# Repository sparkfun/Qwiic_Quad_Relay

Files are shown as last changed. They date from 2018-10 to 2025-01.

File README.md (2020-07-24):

SparkFun Qwiic Quad Relay
========================================

SparkFun Qwiic Quad Relay (https://www.sparkfun.com/products/16566)

[*SparkFun Qwiic Quad Relay (COM-16566)*](https://www.sparkfun.com/products/16566)

The Qwiic Quad Relay is a product designed for switching not one, but **four** high powered devices, from your Arduino or other low powered microcontroller using I<sup>2</sup>C. It's rocking four [relays](https://www.sparkfun.com/products/100) on its' PCB rated up to 5 Amps per channel at 250VAC. Each channel is sporting its own colored LED and silk for easy identification, and has screw terminals for easy connection.  

The board is made to integrate easily into the [Qwiic environment](https://www.sparkfun.com/qwiic) with Qwiic connectors on each side for easy daisy chaining. At the heart of the product is an ATtiny84 with its own I<sup>2</sup>C address awaiting for I<sup>2</sup>C commands that are designated to turn on and off individual channels or _all_ the channels at once! All of this is detailed nicely in provided example code, which also walks you through changing the boards single I<sup>2</sup>C address. There is a four pin header broken out for those of you not taking advantage of the Qwiic connector.

The onboard barrel jack is rated for wall warts in the range, 7-15V but there is a jumper on the underside in the case that your wall wart is 5V. Messing with such high voltage can be dangerous! We've included many safety precautions onto the PCB including, wide traces designed for high amperage, ground isolation between the relay and other circuitry, and a milled out area around the common pin of the relay.

Repository Contents
-------------------

* **/Firmware** - Latest firmware and examples. 
* **/Arduino Example** - Examples on how to use the product with buttons and switches, with hardware interrupts and without.
* **/Hardware** - Eagle design files (.brd, .sch)

Documentation
--------------

* **[Hookup Guide](https://learn.sparkfun.com/tutorials/qwiic-quad-relay-hookup-guide)** - Basic hookup guide

Arduino Library
--------------
* **[SparkFun Qwiic Relay Ardruino Library](https://github.com/sparkfun/SparkFun_Qwiic_Relay_Arduino_Library)** - SparkFun Arduino Library for controlling the Qwiic Single and Quad Relay

License Information
-------------------

This product is _**open source**_! 

Please review the LICENSE.md file for license information. 

If you have any questions or concerns on licensing, please contact technical support on our [SparkFun forums](https://forum.sparkfun.com/viewforum.php?f=152).

Please use, reuse, and modify these files as you see fit. Please maintain attribution to SparkFun Electronics and release under the same license.

Distributed as-is; no warranty is given.

- Your friends at SparkFun.

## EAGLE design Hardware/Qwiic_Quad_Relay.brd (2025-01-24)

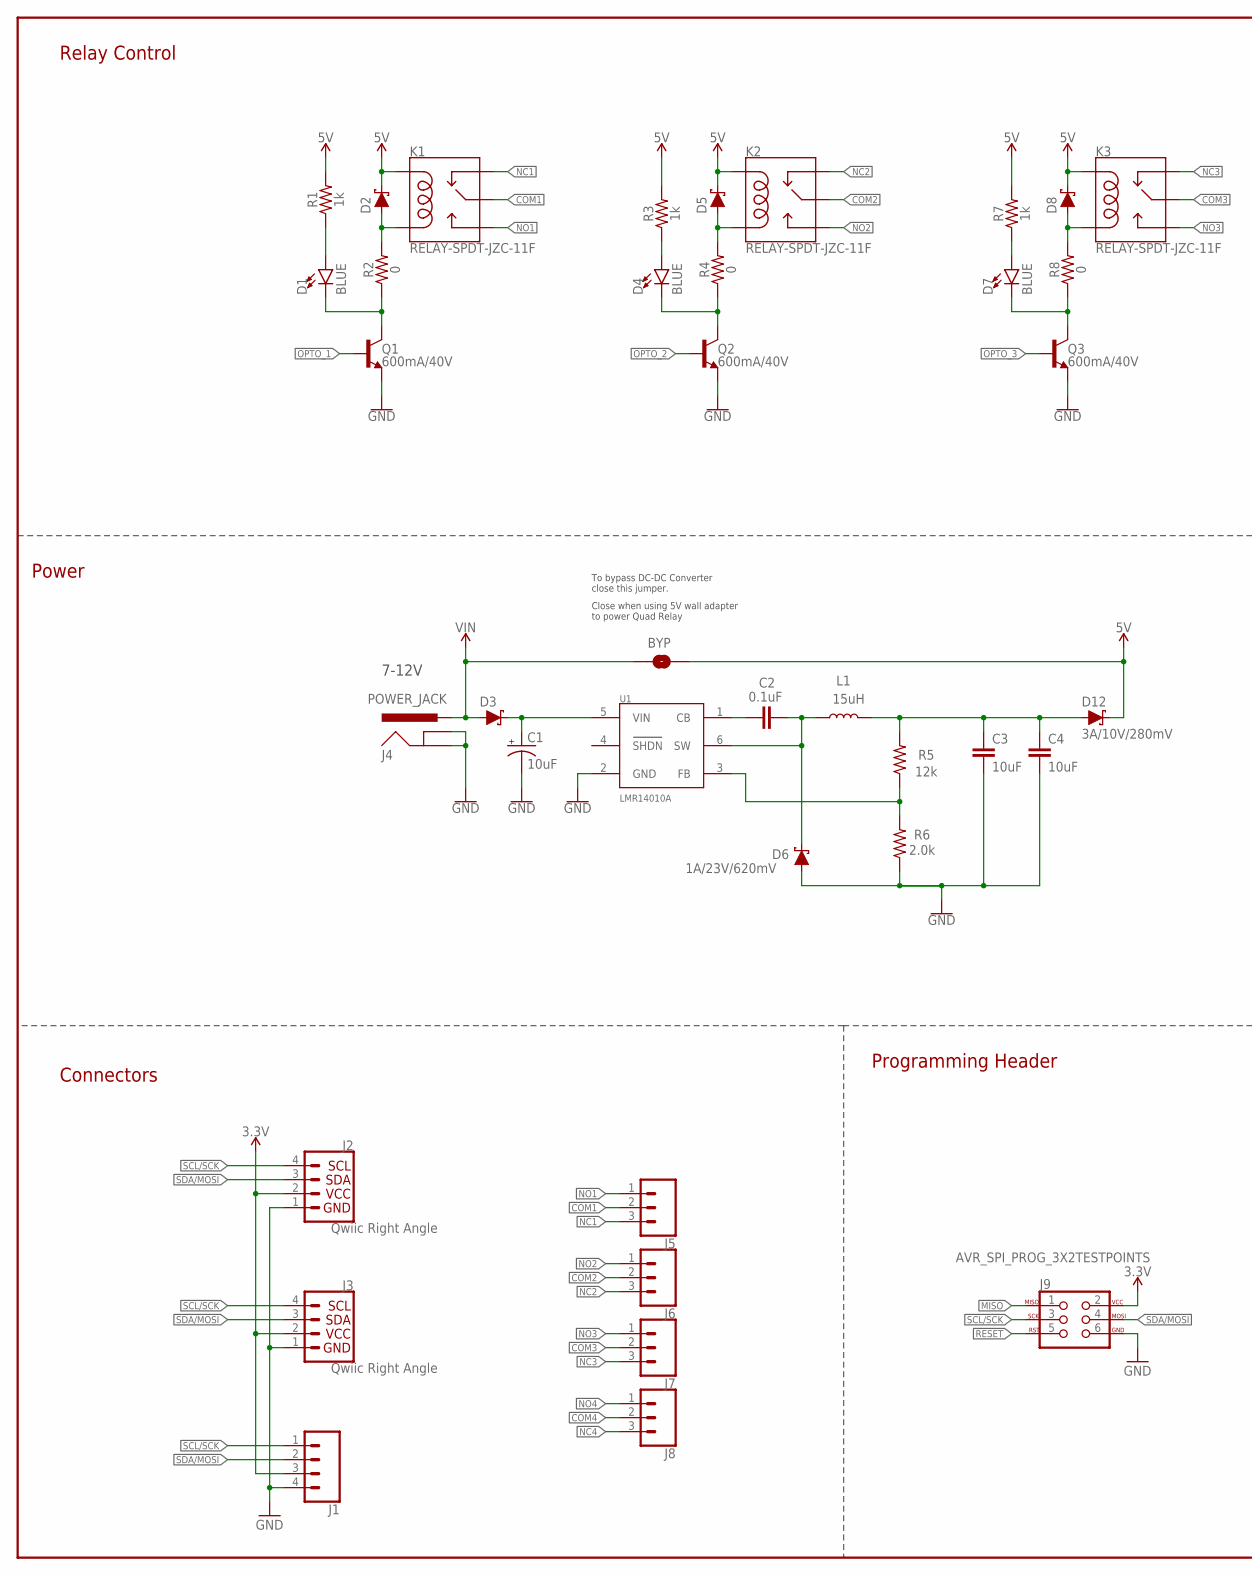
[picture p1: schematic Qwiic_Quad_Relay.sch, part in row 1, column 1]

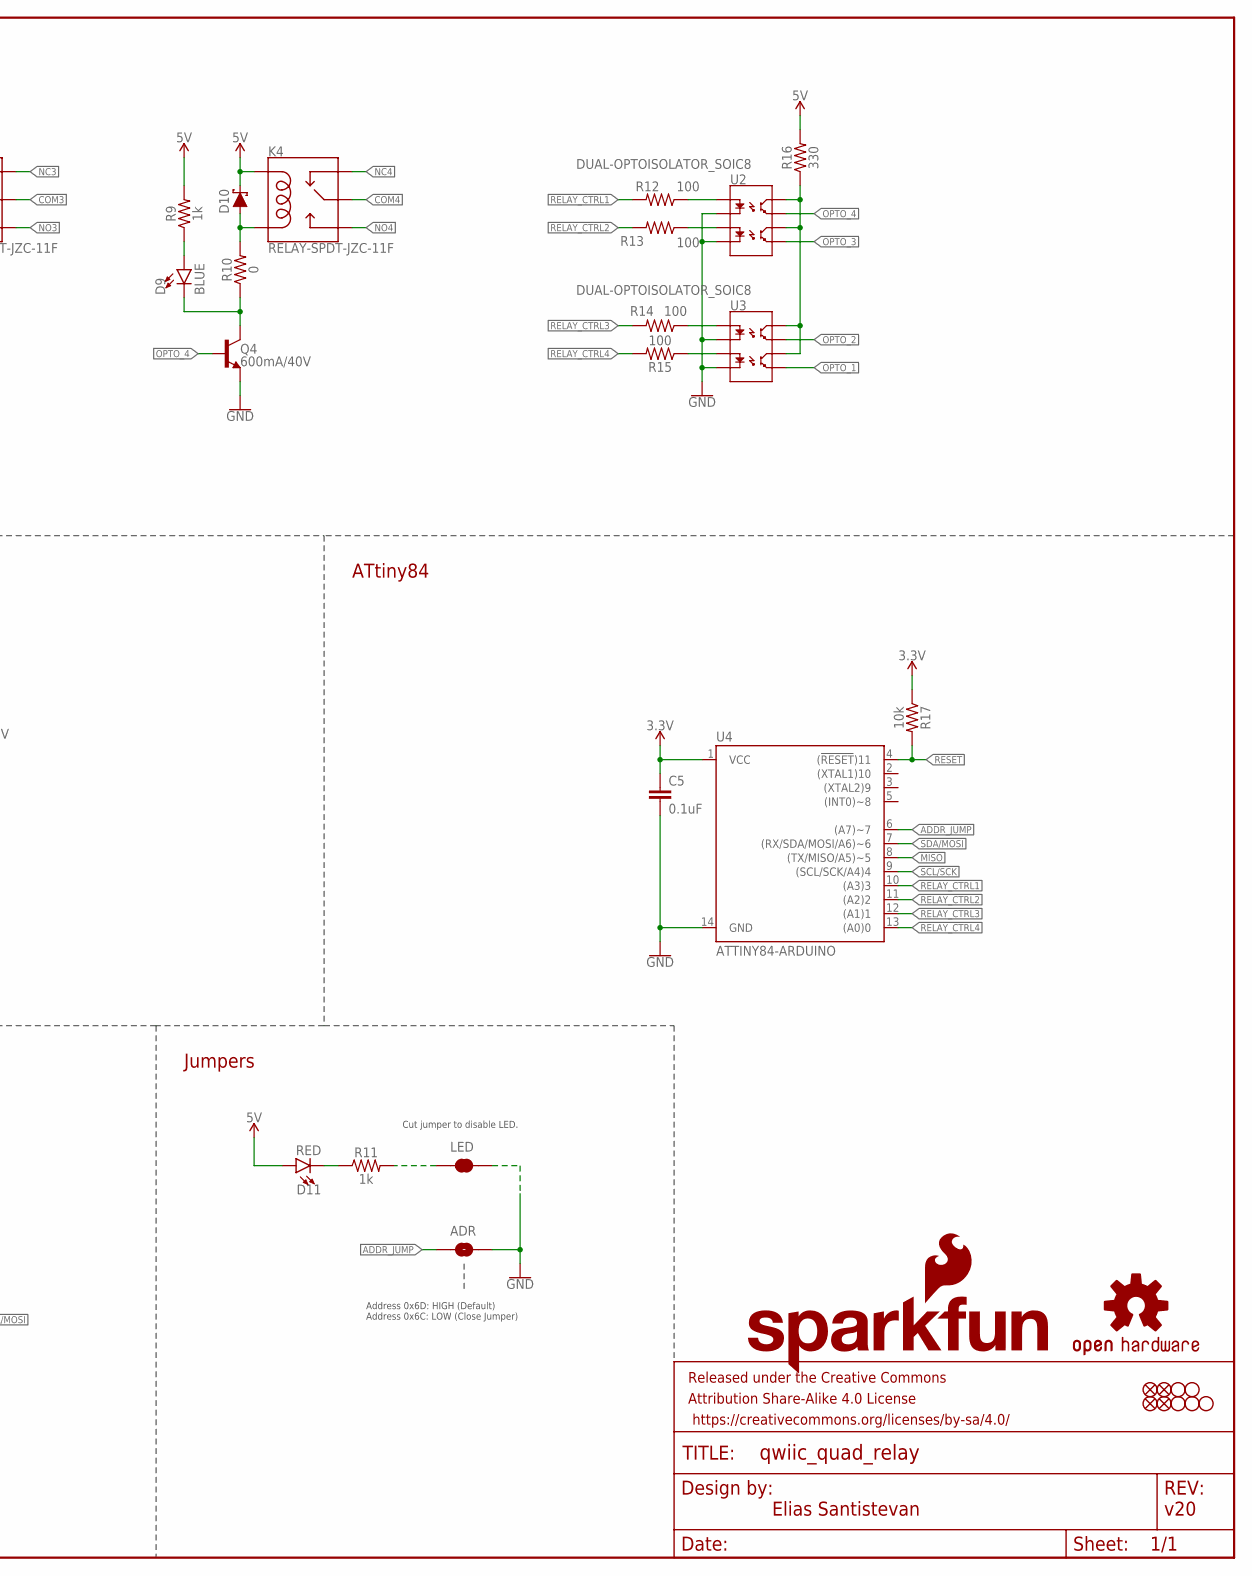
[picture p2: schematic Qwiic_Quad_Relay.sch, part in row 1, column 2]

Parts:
ADR: JUMPER-SMT_2_NO_SILK; SMT-JUMPER_2_NO_SILK
BYP: JUMPER-SMT_2_NO_SILK; SMT-JUMPER_2_NO_SILK
C1: 10uF; EIA3528
C2: 0.1uF; 0402
C3, C4: 10uF; 0603
C5: 0.1uF; 0603
D1, D4, D7, D9: BLUE; LED-0603
D2, D5, D6, D8, D10: 1A/23V/620mV; SOD-323
D3: 1A/40V/500mV; SMA-DIODE
D11: RED; LED-0603
D12: 3A/10V/280mV; SOD-323
FD1, FD2, FD3, FD4: FIDUCIAL1X2; FIDUCIAL-1X2
FRAME1: FRAME-LEDGER; CREATIVE_COMMONS
J1: CONN_041X04_NO_SILK_NO_POP; 1X04_NO_SILK
J2, J3: Qwiic Right Angle; JST04_1MM_RA
J4: POWER_JACK; POWER_JACK_PTH
J5, J6, J7, J8: CONN_03-SCREW-5MM; SCREWTERMINAL-5MM-3
J9: AVR_SPI_PROG_3X2TESTPOINTS; 2X3_TEST_POINTS
JP1, JP4, JP5, JP6, JP7: STAND-OFF
K1, K2, K3, K4: RELAY-SPDT-JZC-11F; RELAY-JZC
L1: 15uH; INDUCTOR_15UH
LED: JUMPER-SMT_2_NC_TRACE_SILK; SMT-JUMPER_2_NC_TRACE_SILK
LOGO1: SFE_LOGO_NAME_FLAME.1_INCH; SFE_LOGO_NAME_FLAME_.1
LOGO2: OSHW-LOGOS; OSHW-LOGO-S
Q1, Q2, Q3, Q4: 600mA/40V; SOT23-3
R1, R3, R7, R9, R11: 1k; 0603
R2, R4, R8, R10: 0; 0603
R5: 12k; 0603
R6: 2.0k; 0603
R12, R13, R14, R15: 100; 0603
R16: 330; 0603
R17: 10k; 0603
U1: LMR14010A; SOT23-6
U2, U3: DUAL-OPTOISOLATOR_SOIC8; SO08
U4: ATTINY84-ARDUINO; SO14

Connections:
3.3V: C5.1, J1.3, J2.2, J3.2, J9.2, R17.1, U4.1 (VCC)
5V: BYP.2, D2.C, D5.C, D8.C, D10.C, D11.A, D12.C, K1.5 (COIL1), K2.5 (COIL1), K3.5 (COIL1), K4.5 (COIL1), R1.2, R3.2, R7.2, R9.2, R16.2
5V_OUT: C3.1, C4.1, D12.A, L1.P2 (2), R5.2
!RESET: J9.5, R17.2, U4.4 ((!RESET!)11)
ADDR_JUMP: ADR.1, U4.6 ((A7)~7)
CB: C2.1, U1.1 (CB)
COM1: J5.2, K1.4 (MAIN)
COM2: J6.2, K2.4 (MAIN)
COM3: J7.2, K3.4 (MAIN)
COM4: J8.2, K4.4 (MAIN)
FB: R5.1, R6.2, U1.3 (FB)
GND: ADR.2, C1.C (-), C3.2, C4.2, C5.2, D6.A, J1.4, J2.1, J3.1, J4.GND, J4.GNDBREAK, J9.6, LED.1, Q1.2 (E), Q2.2 (E), Q3.2 (E), Q4.2 (E), R6.1, U1.2 (GND), U2.2 (C1), U2.4 (C2), U3.2 (C1), U3.4 (C2), U4.14 (GND)
MISO: J9.1, U4.8 ((TX/MISO/A5)~5)
unnamed: D1.A, R1.1
unnamed: D1.C, Q1.3 (C), R2.1
unnamed: R15.1, U3.3 (A2)
unnamed: D4.A, R3.1
unnamed: R14.1, U3.1 (A1)
unnamed: R16.1, U2.6 (CL2), U2.8 (CL1), U3.6 (CL2), U3.8 (CL1)
unnamed: D7.A, R7.1
unnamed: D9.A, R9.1
unnamed: R12.1, U2.1 (A1)
unnamed: D2.A, K1.1 (COIL2), R2.2
unnamed: R13.1, U2.3 (A2)
unnamed: D4.C, Q2.3 (C), R4.1
unnamed: D11.C, R11.1
unnamed: LED.2, R11.2
unnamed: D7.C, Q3.3 (C), R8.1
unnamed: D9.C, Q4.3 (C), R10.1
unnamed: D5.A, K2.1 (COIL2), R4.2
unnamed: D8.A, K3.1 (COIL2), R8.2
unnamed: D10.A, K4.1 (COIL2), R10.2
NC1: J5.3, K1.2 (NC)
NC2: J6.3, K2.2 (NC)
NC3: J7.3, K3.2 (NC)
NC4: J8.3, K4.2 (NC)
NO1: J5.1, K1.3 (NO)
NO2: J6.1, K2.3 (NO)
NO3: J7.1, K3.3 (NO)
NO4: J8.1, K4.3 (NO)
OPTO_1: Q1.1 (B), U3.5 (EM2)
OPTO_2: Q2.1 (B), U3.7 (EM1)
OPTO_3: Q3.1 (B), U2.5 (EM2)
OPTO_4: Q4.1 (B), U2.7 (EM1)
RELAY_CTRL1: R12.2, U4.10 ((A3)3)
RELAY_CTRL2: R13.2, U4.11 ((A2)2)
RELAY_CTRL3: R14.2, U4.12 ((A1)1)
RELAY_CTRL4: R15.2, U4.13 ((A0)0)
SCL/SCK: J1.1, J2.4, J3.4, J9.3, U4.9 ((SCL/SCK/A4)4)
SDA/MOSI: J1.2, J2.3, J3.3, J9.4, U4.7 ((RX/SDA/MOSI/A6)~6)
SW: C2.2, D6.C, L1.P1 (1), U1.6 (SW)
VIN: BYP.1, D3.A, J4.PWR
VIN_DC_DC: C1.A (+), D3.C, U1.5 (VIN)

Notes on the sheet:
Elias Santistevan
v20
Relay Control
Connectors
ATtiny84
Programming Header
Power
Address 0x6D: HIGH (Default) Address 0x6C: LOW (Close Jumper)
7-12V
Cut jumper to disable LED.
Jumpers
To bypass DC-DC Converter close this jumper.
Close when using 5V wall adapter to power Quad Relay

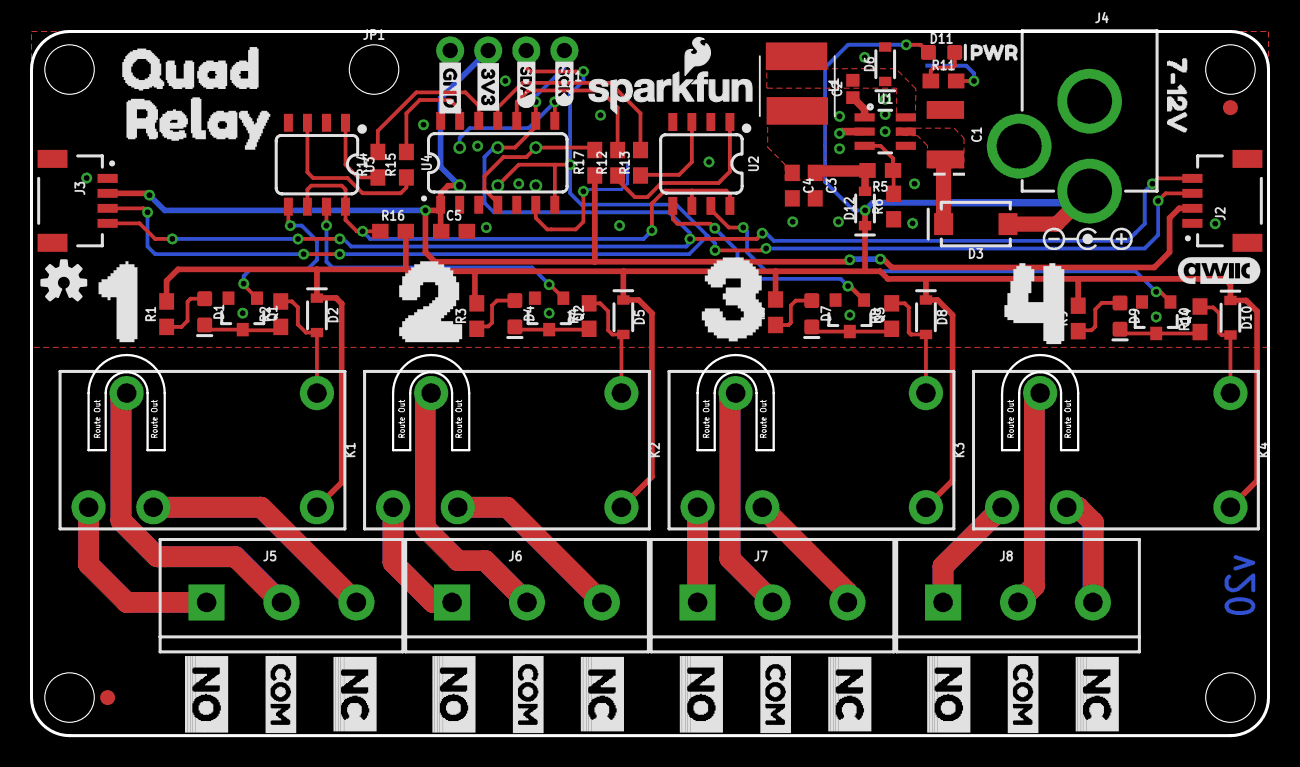
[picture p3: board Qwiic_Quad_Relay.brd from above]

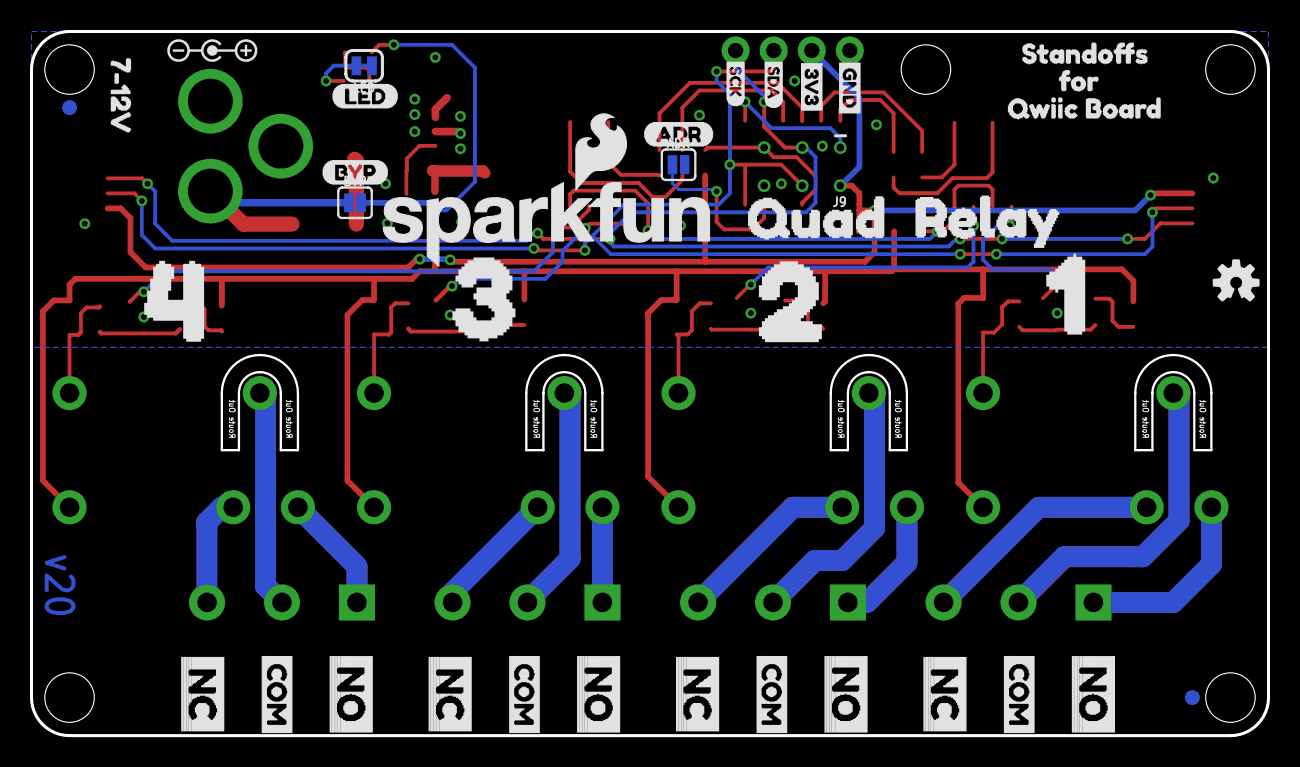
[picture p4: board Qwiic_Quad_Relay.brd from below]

Board: 2 copper layers, 82.5 x 47.0 mm, 129 parts (38 on the bottom side), 53 nets.

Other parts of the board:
U$1, U$49: 7#12V0
U$2, U$40: 20
U$3, U$39: 10
U$4, U$41: 30
U$5, U$42: 40
U$6, U$43: QUAD0
U$7, U$44: RELAY0
U$8, U$48: SCK-[)-03
U$9, U$45: GND-03
U$10, U$12: 3V3-03
U$11, U$47: SDA0
U$13: OSHW-LOGO-S
U$14: BYP
U$15, U$18, U$21, U$24, U$27, U$30, U$33, U$36: NO0
U$16, U$19, U$22, U$25, U$28, U$31, U$34, U$37: COM0
U$17, U$20, U$23, U$26, U$29, U$32, U$35, U$38: NC0
U$46: PWR_TO
U$50: STANDOFFS0
U$51, U$54: POLARITY_MARKING_CENTER_POSITIVE#JPG
U$52: FOR1
U$53: LED
U$55: QWIIC_5.5MM
U$56: ADR-()-04
U$57: SFE_LOGO_NAME_FLAME_.2
U$58: QWIIC_BOARD2

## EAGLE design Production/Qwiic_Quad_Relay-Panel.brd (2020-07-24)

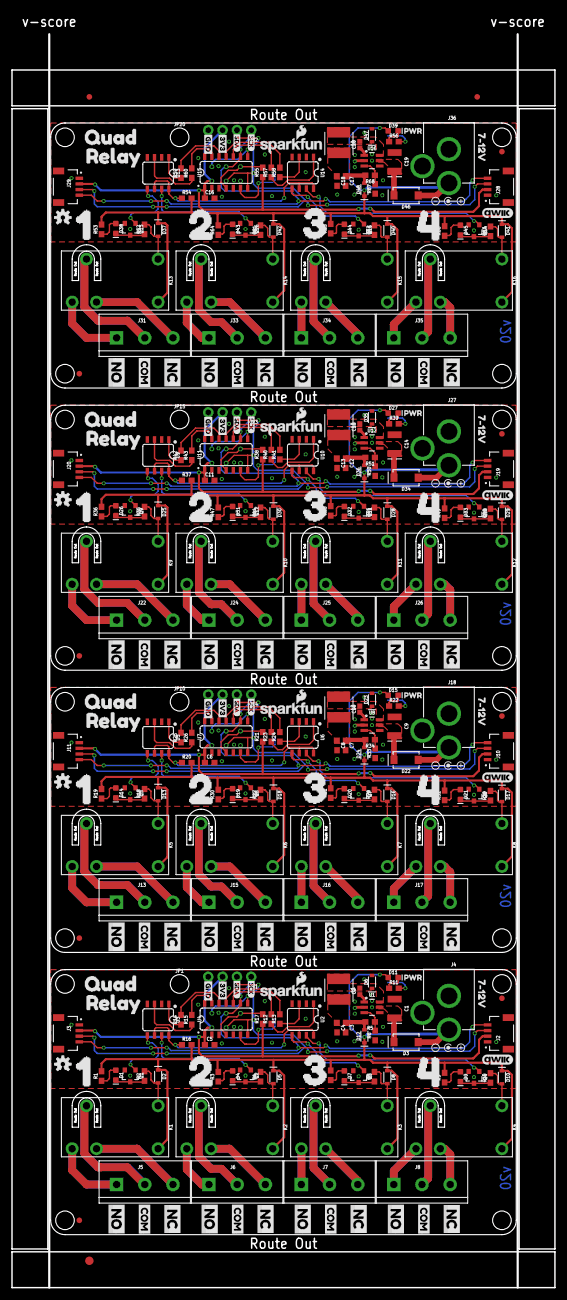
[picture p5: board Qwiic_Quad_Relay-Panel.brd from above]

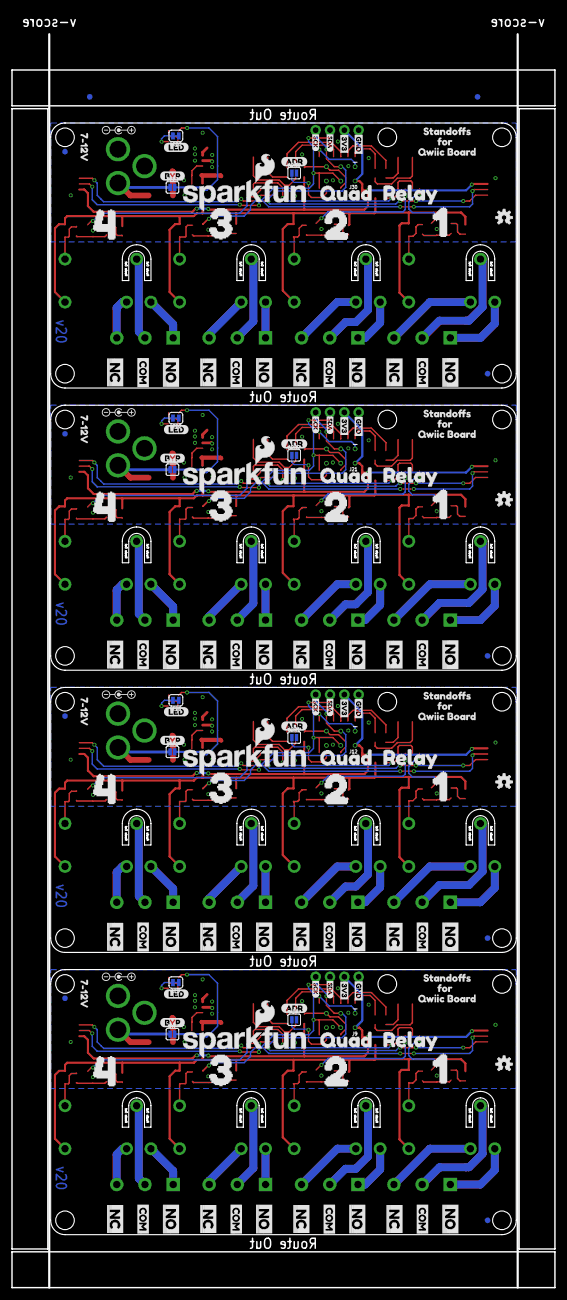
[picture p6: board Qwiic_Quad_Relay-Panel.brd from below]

Board: 2 copper layers, 96.3 x 222.2 mm, 517 parts (154 on the bottom side), 212 nets.

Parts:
ADR, ADR1, ADR2, ADR3: JUMPER-SMT_2_NO_SILK; SMT-JUMPER_2_NO_SILK
BYP, BYP1, BYP2, BYP3: JUMPER-SMT_2_NO_SILK; SMT-JUMPER_2_NO_SILK
C1, C9, C14, C19: 10uF; EIA3528
C2, C10, C15, C20: 0.1uF; 0402
C3, C4, C7, C8, C12, C13, C17, C18: 10uF; 0603
C5, C6, C11, C16: 0.1uF; 0603
D1, D4, D7, D9, D14, D19, D20, D21, D26, D31, D32, D33, D38, D43, D44, D45: BLUE; LED-0603
D2, D5, D8, D10, D13, D16, D17, D18, D25, D28, D29, D30, D37, D40, D41, D42: 1A/23V/620mV; SOD-323
D3, D22, D34, D46: 1A/40V/500mV; SMA-DIODE
D6, D12, D23, D24, D35, D36, D47, D48: 3A/10V/280mV; SOD-323
D11, D15, D27, D39: RED; LED-0603
E$1, E$2, E$3, E$4: FIDUCIAL-1X2
E$5: FIDUCIAL-1.5X3
FD1, FD2, FD3, FD4, FD5, FD6, FD7, FD8, FD9, FD10, FD11, FD12, FD13, FD14, FD15, FD16: FIDUCIAL1X2; FIDUCIAL-1X2
J1, J14, J23, J32: 1X04_NO_SILK
J2, J3, J10, J11, J19, J20, J28, J29: Qwiic Right Angle; JST04_1MM_RA
J4, J18, J27, J36: POWER_JACK; POWER_JACK_PTH
J5, J6, J7, J8, J13, J15, J16, J17, J22, J24, J25, J26, J31, J33, J34, J35: SCREWTERMINAL-5MM-3
J9, J12, J21, J30: AVR_SPI_PROG_3X2TESTPOINTS; 2X3_TEST_POINTS
JP1, JP2, JP3, JP4, JP5, JP6, JP7, JP8, JP9, JP10, JP11, JP12, JP13, JP14, JP15, JP16, JP17, JP18, JP19, JP20: STAND-OFF
K1, K2, K3, K4, K5, K6, K7, K8, K9, K10, K11, K12, K13, K14, K15, K16: RELAY-SPDT-JZC-11F; RELAY-JZC
L1, L2, L3, L4: 15uH; INDUCTOR_15UH
LED, LED1, LED2, LED3: JUMPER-SMT_2_NC_TRACE_SILK; SMT-JUMPER_2_NC_TRACE_SILK
LOGO1, LOGO4, LOGO6, LOGO8: SFE_LOGO_NAME_FLAME.1_INCH; SFE_LOGO_NAME_FLAME_.1
LOGO2, LOGO3, LOGO5, LOGO7: OSHW-LOGOS; OSHW-LOGO-S
Q1, Q2, Q3, Q4, Q5, Q6, Q7, Q8, Q9, Q10, Q11, Q12, Q13, Q14, Q15, Q16: 600mA/40V; SOT23-3
R1, R3, R7, R9, R11, R19, R22, R30, R31, R32, R36, R39, R47, R48, R49, R53, R56, R64, R65, R66: 1k; 0603
R2, R4, R8, R10, R18, R27, R28, R29, R35, R44, R45, R46, R52, R61, R62, R63: 33; 0603
R5, R34, R51, R68: 12k; 0603
R6, R33, R50, R67: 2.0k; 0603
R12, R13, R14, R15, R23, R24, R25, R26, R40, R41, R42, R43, R57, R58, R59, R60: 100; 0603
R16, R20, R37, R54: 330; 0603
R17, R21, R38, R55: 10k; 0603
U1, U8, U12, U16: LMR14010A; SOT23-6
U2, U3, U5, U6, U9, U10, U13, U14: DUAL-OPTOISOLATOR_SOIC8; SO08
U4, U7, U11, U15: ATTINY84-ARDUINO; SO14
U$1, U$49, U$107, U$108, U$165, U$166, U$223, U$224: 7#12V0
U$2, U$40, U$59, U$89, U$117, U$147, U$175, U$205: 20
U$3, U$39, U$60, U$88, U$118, U$146, U$176, U$204: 10
U$4, U$41, U$61, U$90, U$119, U$148, U$177, U$206: 30
U$5, U$42, U$62, U$91, U$120, U$149, U$178, U$207: 40
U$6, U$43, U$110, U$111, U$168, U$169, U$226, U$227: QUAD0
U$7, U$44, U$63, U$92, U$121, U$150, U$179, U$208: RELAY0
U$8, U$48, U$94, U$99, U$152, U$157, U$210, U$215: SCK-[)-03
U$9, U$45, U$95, U$97, U$153, U$155, U$211, U$213: GND-03
U$10, U$12, U$103, U$104, U$161, U$162, U$219, U$220: 3V3-03
U$11, U$47, U$96, U$98, U$154, U$156, U$212, U$214: SDA0
U$13, U$93, U$151, U$209: OSHW-LOGO-S
U$14, U$105, U$163, U$221: BYP
U$15, U$18, U$21, U$24, U$27, U$30, U$33, U$36, U$64, U$67, U$70, U$73, U$76, U$79, U$82, U$85, U$122, U$125, U$128, U$131, U$134, U$137, U$140, U$143, U$180, U$183, U$186, U$189, U$192, U$195, U$198, U$201: NO0
U$16, U$19, U$22, U$25, U$28, U$31, U$34, U$37, U$65, U$68, U$71, U$74, U$77, U$80, U$83, U$86, U$123, U$126, U$129, U$132, U$135, U$138, U$141, U$144, U$181, U$184, U$187, U$190, U$193, U$196, U$199, U$202: COM0
U$17, U$20, U$23, U$26, U$29, U$32, U$35, U$38, U$66, U$69, U$72, U$75, U$78, U$81, U$84, U$87, U$124, U$127, U$130, U$133, U$136, U$139, U$142, U$145, U$182, U$185, U$188, U$191, U$194, U$197, U$200, U$203: NC0
U$46, U$106, U$164, U$222: PWR_TO
U$50, U$114, U$172, U$230: STANDOFFS0
U$51, U$54, U$100, U$101, U$158, U$159, U$216, U$217: POLARITY_MARKING_CENTER_POSITIVE#JPG
U$52, U$115, U$173, U$231: FOR1
U$53, U$112, U$170, U$228: LED
U$55, U$109, U$167, U$225: QWIIC_5.5MM
U$56, U$102, U$160, U$218: ADR-()-04
U$57, U$113, U$171, U$229: SFE_LOGO_NAME_FLAME_.2
U$58, U$116, U$174, U$232: QWIIC_BOARD2

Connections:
3.3V: C5.1, J1.3, J2.2, J3.2, J9.2, R17.1, U4.1
3.3V1: C6.1, J10.2, J11.2, J12.2, J14.3, R21.1, U7.1
3.3V2: C11.1, J19.2, J20.2, J21.2, J23.3, R38.1, U11.1
3.3V3: C16.1, J28.2, J29.2, J30.2, J32.3, R55.1, U15.1
5V: BYP.2, D2.C, D5.C, D8.C, D10.C, D11.A, D12.C, K1.5, K2.5, K3.5, K4.5, R1.2, R3.2, R7.2, R9.2, R16.2
5V1: BYP1.2, D13.C, D15.A, D16.C, D17.C, D18.C, D24.C, K5.5, K6.5, K7.5, K8.5, R19.2, R20.2, R30.2, R31.2, R32.2
5V2: BYP2.2, D25.C, D27.A, D28.C, D29.C, D30.C, D36.C, K9.5, K10.5, K11.5, K12.5, R36.2, R37.2, R47.2, R48.2, R49.2
5V3: BYP3.2, D37.C, D39.A, D40.C, D41.C, D42.C, D48.C, K13.5, K14.5, K15.5, K16.5, R53.2, R54.2, R64.2, R65.2, R66.2
5V_OUT: C3.1, C4.1, D12.A, L1.P2, R5.2
5V_OUT1: C7.1, C8.1, D24.A, L2.P2, R34.2
5V_OUT2: C12.1, C13.1, D36.A, L3.P2, R51.2
5V_OUT3: C17.1, C18.1, D48.A, L4.P2, R68.2
!RESET: J9.5, R17.2, U4.4
!RESET1: J12.5, R21.2, U7.4
!RESET2: J21.5, R38.2, U11.4
!RESET3: J30.5, R55.2, U15.4
ADDR_JUMP: ADR.1, U4.6
ADDR_JUMP1: ADR1.1, U7.6
ADDR_JUMP2: ADR2.1, U11.6
ADDR_JUMP3: ADR3.1, U15.6
CB: C2.1, U1.1
CB1: C10.1, U8.1
CB2: C15.1, U12.1
CB3: C20.1, U16.1
COM1: J5.2, K1.4
COM2: J6.2, K2.4
COM3: J7.2, K3.4
COM4: J8.2, K4.4
COM5: J13.2, K5.4
COM6: J15.2, K6.4
COM7: J16.2, K7.4
COM8: J17.2, K8.4
COM9: J22.2, K9.4
COM10: J24.2, K10.4
COM11: J25.2, K11.4
COM12: J26.2, K12.4
COM13: J31.2, K13.4
COM14: J33.2, K14.4
COM15: J34.2, K15.4
COM16: J35.2, K16.4
FB: R5.1, R6.2, U1.3
FB1: R33.2, R34.1, U8.3
FB2: R50.2, R51.1, U12.3
FB3: R67.2, R68.1, U16.3
GND: ADR.2, C1.C, C3.2, C4.2, C5.2, D6.A, J1.4, J2.1, J3.1, J4.GND, J4.GNDBREAK, J9.6, LED.1, Q1.2, Q2.2, Q3.2, Q4.2, R6.1, U1.2, U2.2, U2.4, U3.2, U3.4, U4.14
GND1: ADR1.2, C6.2, C7.2, C8.2, C9.C, D23.A, J10.1, J11.1, J12.6, J14.4, J18.GND, J18.GNDBREAK, LED1.1, Q5.2, Q6.2, Q7.2, Q8.2, R33.1, U5.2, U5.4, U6.2, U6.4, U7.14, U8.2
GND2: ADR2.2, C11.2, C12.2, C13.2, C14.C, D35.A, J19.1, J20.1, J21.6, J23.4, J27.GND, J27.GNDBREAK, LED2.1, Q9.2, Q10.2, Q11.2, Q12.2, R50.1, U9.2, U9.4, U10.2, U10.4, U11.14, U12.2
GND3: ADR3.2, C16.2, C17.2, C18.2, C19.C, D47.A, J28.1, J29.1, J30.6, J32.4, J36.GND, J36.GNDBREAK, LED3.1, Q13.2, Q14.2, Q15.2, Q16.2, R67.1, U13.2, U13.4, U14.2, U14.4, U15.14, U16.2
MISO: J9.1, U4.8
MISO1: J12.1, U7.8
MISO2: J21.1, U11.8
MISO3: J30.1, U15.8
unnamed: D1.A, R1.1
unnamed: D1.C, Q1.3, R2.1
unnamed: R15.1, U3.3
unnamed: D4.A, R3.1
unnamed: R14.1, U3.1
unnamed: R16.1, U2.6, U2.8, U3.6, U3.8
unnamed: D7.A, R7.1
unnamed: D9.A, R9.1
unnamed: R12.1, U2.1
unnamed: D2.A, K1.1, R2.2
unnamed: R13.1, U2.3
unnamed: D4.C, Q2.3, R4.1
unnamed: D11.C, R11.1
unnamed: LED.2, R11.2
unnamed: D7.C, Q3.3, R8.1
unnamed: D14.C, Q5.3, R18.1
unnamed: D9.C, Q4.3, R10.1
unnamed: D5.A, K2.1, R4.2
unnamed: D15.C, R22.1
unnamed: R26.1, U5.3
unnamed: R25.1, U5.1
unnamed: R20.1, U5.6, U5.8, U6.6, U6.8
unnamed: D8.A, K3.1, R8.2
unnamed: D10.A, K4.1, R10.2
unnamed: R23.1, U6.1
unnamed: R24.1, U6.3
unnamed: D19.C, Q8.3, R27.1
unnamed: D20.C, Q7.3, R28.1
unnamed: D21.C, Q6.3, R29.1
unnamed: D13.A, K5.1, R18.2
unnamed: D18.A, K6.1, R27.2
unnamed: D16.A, K7.1, R28.2
unnamed: D17.A, K8.1, R29.2
unnamed: LED1.2, R22.2
unnamed: D14.A, R19.1
unnamed: D19.A, R30.1
unnamed: D20.A, R31.1
unnamed: D21.A, R32.1
unnamed: D26.C, Q9.3, R35.1
unnamed: D27.C, R39.1
unnamed: R43.1, U9.3
unnamed: R42.1, U9.1
unnamed: R37.1, U9.6, U9.8, U10.6, U10.8
unnamed: R40.1, U10.1
unnamed: R41.1, U10.3
unnamed: D31.C, Q12.3, R44.1
unnamed: D32.C, Q11.3, R45.1
unnamed: D33.C, Q10.3, R46.1
unnamed: D25.A, K9.1, R35.2
unnamed: D30.A, K10.1, R44.2
unnamed: D28.A, K11.1, R45.2
unnamed: D29.A, K12.1, R46.2
unnamed: LED2.2, R39.2
unnamed: D26.A, R36.1
unnamed: D31.A, R47.1
unnamed: D32.A, R48.1
unnamed: D33.A, R49.1
unnamed: D38.C, Q13.3, R52.1
unnamed: D39.C, R56.1
unnamed: R60.1, U13.3
unnamed: R59.1, U13.1
unnamed: R54.1, U13.6, U13.8, U14.6, U14.8
unnamed: R57.1, U14.1
unnamed: R58.1, U14.3
unnamed: D43.C, Q16.3, R61.1
unnamed: D44.C, Q15.3, R62.1
unnamed: D45.C, Q14.3, R63.1
unnamed: D37.A, K13.1, R52.2
unnamed: D42.A, K14.1, R61.2
unnamed: D40.A, K15.1, R62.2
unnamed: D41.A, K16.1, R63.2
unnamed: LED3.2, R56.2
unnamed: D38.A, R53.1
unnamed: D43.A, R64.1
unnamed: D44.A, R65.1
unnamed: D45.A, R66.1
NC1: J5.3, K1.2
NC2: J6.3, K2.2
NC3: J7.3, K3.2
NC4: J8.3, K4.2
NC5: J13.3, K5.2
NC6: J15.3, K6.2
NC7: J16.3, K7.2
NC8: J17.3, K8.2
NC9: J22.3, K9.2
NC10: J24.3, K10.2
NC11: J25.3, K11.2
NC12: J26.3, K12.2
NC13: J31.3, K13.2
NC14: J33.3, K14.2
NC15: J34.3, K15.2
NC16: J35.3, K16.2
NO1: J5.1, K1.3
NO2: J6.1, K2.3
NO3: J7.1, K3.3
NO4: J8.1, K4.3
NO5: J13.1, K5.3
NO6: J15.1, K6.3
NO7: J16.1, K7.3
NO8: J17.1, K8.3
NO9: J22.1, K9.3
NO10: J24.1, K10.3
NO11: J25.1, K11.3
NO12: J26.1, K12.3
NO13: J31.1, K13.3
NO14: J33.1, K14.3
NO15: J34.1, K15.3
NO16: J35.1, K16.3
OPTO_1: Q1.1, U3.5
OPTO_2: Q2.1, U3.7
OPTO_3: Q3.1, U2.5
OPTO_4: Q4.1, U2.7
OPTO_5: Q5.1, U5.5
OPTO_6: Q8.1, U5.7
OPTO_7: Q7.1, U6.5
OPTO_8: Q6.1, U6.7
OPTO_9: Q9.1, U9.5
OPTO_10: Q12.1, U9.7
OPTO_11: Q11.1, U10.5
OPTO_12: Q10.1, U10.7
OPTO_13: Q13.1, U13.5
OPTO_14: Q16.1, U13.7
OPTO_15: Q15.1, U14.5
OPTO_16: Q14.1, U14.7
RELAY_CTRL1: R12.2, U4.10
RELAY_CTRL2: R13.2, U4.11
RELAY_CTRL3: R14.2, U4.12
RELAY_CTRL4: R15.2, U4.13
RELAY_CTRL5: R23.2, U7.10
RELAY_CTRL6: R24.2, U7.11
RELAY_CTRL7: R25.2, U7.12
RELAY_CTRL8: R26.2, U7.13
RELAY_CTRL9: R40.2, U11.10
RELAY_CTRL10: R41.2, U11.11
RELAY_CTRL11: R42.2, U11.12
RELAY_CTRL12: R43.2, U11.13
RELAY_CTRL13: R57.2, U15.10
RELAY_CTRL14: R58.2, U15.11
RELAY_CTRL15: R59.2, U15.12
RELAY_CTRL16: R60.2, U15.13
SCL/SCK: J1.1, J2.4, J3.4, J9.3, U4.9
SCL/SCK1: J10.4, J11.4, J12.3, J14.1, U7.9
SCL/SCK2: J19.4, J20.4, J21.3, J23.1, U11.9
SCL/SCK3: J28.4, J29.4, J30.3, J32.1, U15.9
SDA/MOSI: J1.2, J2.3, J3.3, J9.4, U4.7
SDA/MOSI1: J10.3, J11.3, J12.4, J14.2, U7.7
SDA/MOSI2: J19.3, J20.3, J21.4, J23.2, U11.7
SDA/MOSI3: J28.3, J29.3, J30.4, J32.2, U15.7
SW: C2.2, D6.C, L1.P1, U1.6
SW1: C10.2, D23.C, L2.P1, U8.6
SW2: C15.2, D35.C, L3.P1, U12.6
SW3: C20.2, D47.C, L4.P1, U16.6
VIN: BYP.1, D3.A, J4.PWR
VIN1: BYP1.1, D22.A, J18.PWR
VIN2: BYP2.1, D34.A, J27.PWR
VIN3: BYP3.1, D46.A, J36.PWR
VIN_DC_DC: C1.A, D3.C, U1.5
VIN_DC_DC1: C9.A, D22.C, U8.5
VIN_DC_DC2: C14.A, D34.C, U12.5
VIN_DC_DC3: C19.A, D46.C, U16.5

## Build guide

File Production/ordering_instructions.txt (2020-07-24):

panel size, 97x207mm
PCB thickness, 1.6mm
number of layers, 2
soldermask color, Red
silkscreen color, White
oz copper, 1oz
finish, HASL lead free
stencils, top+bottom
pcs per panel, 4
min trace width, 0.2032mm / 0.0080in
min drill size, 0.3810mm / 0.0150in

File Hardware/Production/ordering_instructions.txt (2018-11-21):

panel size, 97x216mm
PCB thickness, 1.6mm
number of layers, 2
soldermask color, Red
silkscreen color, White
oz copper, 1oz
finish, HASL lead free
stencils, none
pcs per panel, 4

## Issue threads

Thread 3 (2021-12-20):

Incorrect Qwiic Quad Relay Firmware Comments

dlkeng, 2021-12-20:
In the file "Qwiic_Quad_Relay_Firmware.ino", there are a couple of comments that are not correct:

1. Line 2 states that this code is for "An I2C based KeyPad" when in reality, it's for the "Qwiic Quad Relay"
2. Lines 206 to 208 state

> "If you request the state of three relays, starting with four, you'll get four(0x08), one(0x05), two(0x06)"

 when in reality, the code **only** returns the state of relay four followed by 2 bytes of 0xff indicating invalid relay items. It does not wrap back to the first relay since there is only one _requestEvent()_ occurring for the multiple bytes requested. However, any subsequent follow-on requests will start from relay one.

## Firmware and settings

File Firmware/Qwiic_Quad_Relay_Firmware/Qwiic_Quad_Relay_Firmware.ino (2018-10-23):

/*
  An I2C based KeyPad
  By: Elias Santistevan
  SparkFun Electronics
  Date: October 2018
  License: This code is public domain but you buy me a beer if you use this and we meet someday (Beerware license).

  Feel like supporting our work? Buy a board from SparkFun!
	<Product Page Here>

  To install support for ATtiny84 in Arduino IDE: https://github.com/SpenceKonde/ATTinyCore/blob/master/Installation.md
  This core is installed from the Board Manager menu
  This core has built in support for I2C S/M and serial
  If you have Dave Mellis' ATtiny installed you may need to remove it from \Users\xx\AppData\Local\Arduino15\Packages

  To support 400kHz I2C communication reliably ATtiny84 needs to run at 8MHz. This requires user to
  click on 'Burn Bootloader' before code is loaded.
*/

#include <Wire.h>

#include <EEPROM.h>

#define LOCATION_I2C_ADDRESS 0x01 //Location in EEPROM where the I2C address is stored
#define I2C_ADDRESS_DEFAULT 109 //0x6D Default address
#define I2C_ADDRESS_JUMPER 108 //0x6C Address if address jumper is closed

#define COMMAND_CHANGE_ADDRESS 0xC7

// Commands that toggle the relays.
#define RELAY_ONE_TOGGLE 0x01
#define RELAY_TWO_TOGGLE 0x02
#define RELAY_THREE_TOGGLE 0x03
#define RELAY_FOUR_TOGGLE 0x04
#define TURN_ALL_OFF 0xA 
#define TURN_ALL_ON 0xB 
#define TOGGLE_ALL 0xC

// Commands to request the state of the relay, whether it is currently on or
// off. 
#define RELAY_STATUS_ONE  0x05 
#define RELAY_STATUS_TWO  0x06
#define RELAY_STATUS_THREE 0x07
#define RELAY_STATUS_FOUR 0x08

// Messages for requests that state whether a relay is on or off. 
#define RELAY_IS_ON 0xF
#define RELAY_IS_OFF 0x0

volatile uint8_t setting_i2c_address = I2C_ADDRESS_DEFAULT; 
volatile uint8_t COMMAND;  //Variable for incoming I2C commands. 

const uint8_t addrPin = 7; 
const uint8_t resetPin = 11; 

// The four relay pins on the ATtiny84A.
const uint8_t relayCtrl1 = 0; 
const uint8_t relayCtrl2 = 1; 
const uint8_t relayCtrl3 = 2; 
const uint8_t relayCtrl4 = 3; 

// This 'status' array keeps track of the state of the relays. 
uint8_t status[] = {RELAY_IS_OFF, RELAY_IS_OFF, RELAY_IS_OFF, RELAY_IS_OFF};

void setup(void)
{
  pinMode(addrPin, INPUT_PULLUP); //Default HIGH = 0x6D or 109
  pinMode(resetPin, INPUT_PULLUP);

  pinMode(relayCtrl1, OUTPUT); //Relay pins to OUTPUT
  pinMode(relayCtrl2, OUTPUT);
  pinMode(relayCtrl3, OUTPUT);
  pinMode(relayCtrl4, OUTPUT);

  readSystemSettings(); //Load all system settings from EEPROM
  startI2C(); //Determine the I2C address we should be using and begin listening on I2C bus
}

void loop(void) {
}

void receiveEvent(int numberOfBytesReceived)
{
  while( Wire.available() ) {
    //Record uint8_ts to local array
    COMMAND = Wire.read();

    if(COMMAND == COMMAND_CHANGE_ADDRESS){ //Set new I2C address 
      if(Wire.available()) {
        setting_i2c_address = Wire.read();

        //Error check
        if(setting_i2c_address < 0x08 || setting_i2c_address > 0x77)
          continue; //Command failed. This address is out of bounds.

        EEPROM.write(LOCATION_I2C_ADDRESS, setting_i2c_address);

        //Our I2C address may have changed because of user's command
        startI2C(); //Determine the I2C address we should be using and begin listening on I2C bus
      }
    }

    // Relay control for relay 1, check the state, toggle the relay, change the
    // state.
    else if(COMMAND == RELAY_ONE_TOGGLE){
      if(status[0] == RELAY_IS_OFF){
        digitalWrite(relayCtrl1, HIGH); 
        status[0] = RELAY_IS_ON; 
      }
      else if(status[0] == RELAY_IS_ON ){
        digitalWrite(relayCtrl1, LOW); 
        status[0] = RELAY_IS_OFF; 
      }
    }

    // Relay control for relay 2, check the state, toggle the relay, change the
    // state.
    else if(COMMAND == RELAY_TWO_TOGGLE){
      if(status[1] == RELAY_IS_OFF){
        digitalWrite(relayCtrl2, HIGH); 
        status[1] = RELAY_IS_ON; 
      }
      else if(status[1] == RELAY_IS_ON ){
        digitalWrite(relayCtrl2, LOW); 
        status[1] = RELAY_IS_OFF; 
      }
    }

    // Relay control for relay 3, check the state, toggle the relay, change the
    // state.
    else if(COMMAND == RELAY_THREE_TOGGLE){
      if(status[2] == RELAY_IS_OFF){
        digitalWrite(relayCtrl3, HIGH); 
        status[2] = RELAY_IS_ON; 
      }
      else if(status[2] == RELAY_IS_ON ){
        digitalWrite(relayCtrl3, LOW); 
        status[2] = RELAY_IS_OFF; 
      }
    }

    // Relay control for relay 4, check the state, toggle the relay, change the
    // state.
    else if(COMMAND == RELAY_FOUR_TOGGLE){
      if(status[3] == RELAY_IS_OFF){
        digitalWrite(relayCtrl4, HIGH); 
        status[3] = RELAY_IS_ON; 
      }
      else if(status[3] == RELAY_IS_ON ){
        digitalWrite(relayCtrl4, LOW); 
        status[3] = RELAY_IS_OFF; 
      }
    }

    // Turn all relays off, record all of their states. 
    else if(COMMAND == TURN_ALL_OFF){
      digitalWrite(relayCtrl1, LOW); 
      digitalWrite(relayCtrl2, LOW); 
      digitalWrite(relayCtrl3, LOW); 
      digitalWrite(relayCtrl4, LOW); 
      for(int i = 0; i < sizeof(status); i++){
        status[i] = RELAY_IS_OFF;
      }
    }

    // Turn it up to ELEVEN, all on! Record their states to the status array.
    else if(COMMAND == TURN_ALL_ON){
      digitalWrite(relayCtrl1, HIGH); 
      digitalWrite(relayCtrl2, HIGH); 
      digitalWrite(relayCtrl3, HIGH); 
      digitalWrite(relayCtrl4, HIGH); 
      for(int i = 0; i < sizeof(status); i++){
        status[i] = RELAY_IS_ON;
      }
    }

    // This command will put each relay into it's opposite state: relays that
    // are on will be turned off and vice versa. 
    else if(COMMAND == TOGGLE_ALL){
      for(int i = 0; i < sizeof(status); i++){
        if(status[i] == RELAY_IS_ON){
          // Remember that the relays are on pins 0-4, which aligns with the
          // status array. With that, I'll be using the iterator 'i' to write
          // the pins HIGH and LOW. 
          digitalWrite(i, LOW); 
          status[i] = RELAY_IS_OFF;
          continue; 
        }
        //Would be an else statement, but for clarity....
        else if(status[i] == RELAY_IS_OFF){
          digitalWrite(i, HIGH);
          status[i] = RELAY_IS_ON;
        }
      }
    }

  }
}

void requestEvent()
{
  // In the you want to request multiple relay states without having to do
  // multiple "requestFrom"'s in code, the request COMMAND will iterate through
  // the sequential response commands (0x05 -> 0x08). For example, if you
  // request 2 bytes, starting with relay three (0x07), then you'll receive the
  // state of relay three and relay four(0x08). If you request the state of
  // three relays, starting with four, you'll get four(0x08), one(0x05),
  // two(0x06) etc.
  if(COMMAND == RELAY_STATUS_ONE){
      Wire.write(status[0]);
      COMMAND++; 
  }
  if(COMMAND == RELAY_STATUS_TWO){
      Wire.write(status[1]);
      COMMAND++;
  }
  if(COMMAND == RELAY_STATUS_THREE){
      Wire.write(status[2]);
      COMMAND++; 
  } 
  if(COMMAND == RELAY_STATUS_FOUR){
      Wire.write(status[3]);
      COMMAND = 0x05; 
  }
}

void readSystemSettings(void)
{
  //Read what I2C address we should use
  setting_i2c_address = EEPROM.read(LOCATION_I2C_ADDRESS);
  if(setting_i2c_address == 255) {
    setting_i2c_address = I2C_ADDRESS_DEFAULT; //By default, we listen for I2C_ADDRESS_DEFAULT
    EEPROM.write(LOCATION_I2C_ADDRESS, setting_i2c_address);
  }
}

//Begin listening on I2C bus as I2C slave using the global variable setting_i2c_address
void startI2C()
{
  Wire.end(); //Before we can change addresses we need to stop
  
  if(digitalRead(addrPin) == HIGH) //Default HIGH
    Wire.begin(setting_i2c_address); //Start I2C and answer calls using address from EEPROM
  else
    Wire.begin(I2C_ADDRESS_JUMPER);//Closed jumper is LOW

  //The connections to the interrupts are severed when a Wire.begin occurs. So re-declare them.
  Wire.onReceive(receiveEvent);
  Wire.onRequest(requestEvent);
}

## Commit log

2018-11-13 Updated to v10 and updated example code that adds commented out line for second i2c address
    [Qwiic_Quad_Relay.brd, Qwiic_Quad_Relay.sch]
2018-11-15 Reduces current consumption on every relay channel, seperates 3.3V and 5V system
    *Current consumption:
    -10 Ohm coil resistor changed to 33 Ohm
    -220 Ohm reistor into base of NPN changed to 330
    *3.3V Qwiic System:
    -Put ATtiny84 back onto the 3.3V Qwiic System
    -Changed OptoIsolator resistors from 220 Ohm to 100 Ohm to hit current requirements
    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
    [Qwiic_Quad_Relay.brd, Qwiic_Quad_Relay.sch]
2018-11-15 Adds selective soldering path to documents layer
    [Qwiic_Quad_Relay.brd, Qwiic_Quad_Relay.sch]
2018-11-19 Changed route out layer from milling to Dimension
    [Qwiic_Quad_Relay.brd]
2018-12-14 Changes fuses to add brown out detection
2019-07-02 Removes Example Code from Hardware library which has been moved to SparkFun Qwiic Relay Arduino Library
2019-07-02 Fixes Readme image and puts link to Arduino library, also in README
2019-07-02 Updates the text on the Arduino library
2020-04-06 Moves 33 Ohm resistor to after the coil so that drop doesn't occur before it.
    [Qwiic_Quad_Relay.brd, Qwiic_Quad_Relay.sch]
2020-04-06 Adds circuitry for DC-DC converter (no traces routed)
    [Qwiic_Quad_Relay.brd, Qwiic_Quad_Relay.sch]
2020-04-07 Re-adds dc-dc converter circuitry - somehow it was not in the last push
    [Qwiic_Quad_Relay.brd, Qwiic_Quad_Relay.sch]
2020-04-07 Routes new circuitry
    [Qwiic_Quad_Relay.brd, Qwiic_Quad_Relay.sch]
2020-04-07 Fixes various minor DRC issues
    [Qwiic_Quad_Relay.brd]
2020-04-07 Adds polygons for switch pin and VIN
    [Qwiic_Quad_Relay.brd]
2020-04-08 Updates inductor with inductor with correct amperage rating
    [Qwiic_Quad_Relay.brd, Qwiic_Quad_Relay.sch]
2020-04-08 Adjusts silk, add bypass jumper, corrects feedback pin resistor values -> output: 5.35V
    [Qwiic_Quad_Relay.brd, Qwiic_Quad_Relay.sch]
2020-04-08 Updates schematic
    [Qwiic_Quad_Relay.brd, Qwiic_Quad_Relay.sch]
2020-04-08 Adds correct inductor
    [Qwiic_Quad_Relay.brd, Qwiic_Quad_Relay.sch]
2020-04-08 Changes standoff to the one used in the SparkFun libraries
    [Qwiic_Quad_Relay.brd, Qwiic_Quad_Relay.sch]
2020-04-08 Fixes bypass
    [Qwiic_Quad_Relay.brd, Qwiic_Quad_Relay.sch]
2020-04-09 Adds better silk, additional standoff, schotkky diode to protect dc/dc converter circuit
    [Qwiic_Quad_Relay.brd, Qwiic_Quad_Relay.sch]
2020-04-09 Fixes inductor
    [Qwiic_Quad_Relay.brd, Qwiic_Quad_Relay.sch]
2020-04-09 Adds silk to indicate qwiic board standoffs
    [Qwiic_Quad_Relay.brd, Qwiic_Quad_Relay.sch]
2020-04-09 Removes Buzzard lables and old production files
    [Qwiic_Quad_Relay-Panel.brd, Qwiic_Quad_Relay.brd]
2020-04-09 Adds new panel
    [Qwiic_Quad_Relay-Panel.GBL, Qwiic_Quad_Relay-Panel.GBO, Qwiic_Quad_Relay-Panel.GBP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]
2020-05-26 Changes LED jumper to normally closed with trace
    [Qwiic_Quad_Relay.brd, Qwiic_Quad_Relay.sch]
2020-05-26 Updates production panel following latest commit
    [Qwiic_Quad_Relay-Panel.brd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]
2020-06-30 Replaces 33 Ohm resistors with 0 Ohm
    [Qwiic_Quad_Relay.brd, Qwiic_Quad_Relay.sch]
2025-01-24 Replaces clamping diode with something more suitable to stated maximum input voltage of the product.
    [Qwiic_Quad_Relay.brd, Qwiic_Quad_Relay.sch]

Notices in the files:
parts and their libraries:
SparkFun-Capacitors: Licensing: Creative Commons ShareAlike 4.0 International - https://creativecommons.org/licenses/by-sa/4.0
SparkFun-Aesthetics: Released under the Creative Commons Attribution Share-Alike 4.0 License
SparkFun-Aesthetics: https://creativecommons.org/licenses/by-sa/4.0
